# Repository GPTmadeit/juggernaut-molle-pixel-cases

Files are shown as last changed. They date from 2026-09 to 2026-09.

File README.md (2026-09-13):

# Juggernaut-style MOLLE case — Pixel 9 Pro, Pixel 9a and Pixel 6a

Three 3D-printable rugged phone cases that drop into the **unmodified** MOLLE adapter from
msenturk115's *Juggernaut Tactical MOLLE Phone Case*, which was drawn around a Galaxy S8.

Each case was rebuilt around a real 3D model of the phone. Every fit — the adapter, the phone,
the end caps, the button plungers — is verified by boolean intersection, not by eye.
**One printed adapter takes any of the three.**

| | Pixel 9 Pro | Pixel 9a | Pixel 6a |
|---|---|---|---|
| phone | 152.80 × 72.00 × 8.50 mm, R 12.00 | 154.70 × 73.30 × 8.90 mm, R 12.03 | 152.20 × 71.79 × 8.90 mm, R 5.2–5.4 |
| camera | 64.4 × 21.5 mm bar, **3.52 mm proud** | 31.2 × 18.0 mm pill, 0.6 mm proud | 66.9 × 16.7 mm visor, 1.5 mm proud |
| case | 164.43 × 86.59 × 19.00 mm | 166.34 × 86.59 × 17.60 mm | 163.83 × 86.59 × 17.20 mm |
| pocket | 154.00 × 72.90 × 8.80 mm | 155.90 × 74.20 × 9.20 mm | 153.40 × 72.69 × 9.20 mm |
| side wall | 2.55 mm | 1.90 mm | 2.66 mm |
| stretch vs. the S8 original | +3.50 mm | +5.40 mm | +2.90 mm |

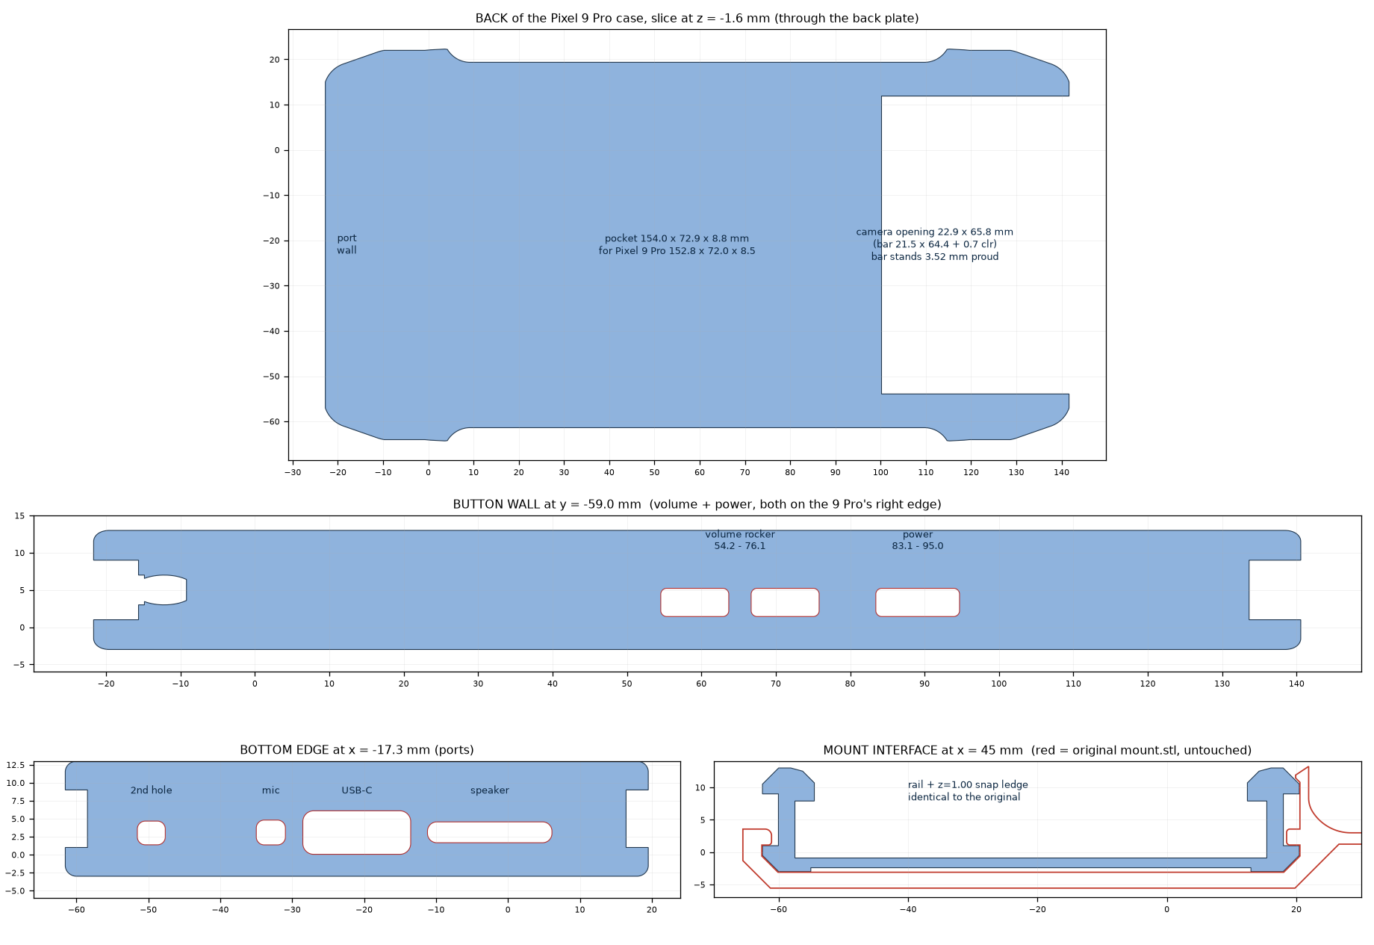
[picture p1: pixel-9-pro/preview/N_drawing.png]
Pixel 9 Pro

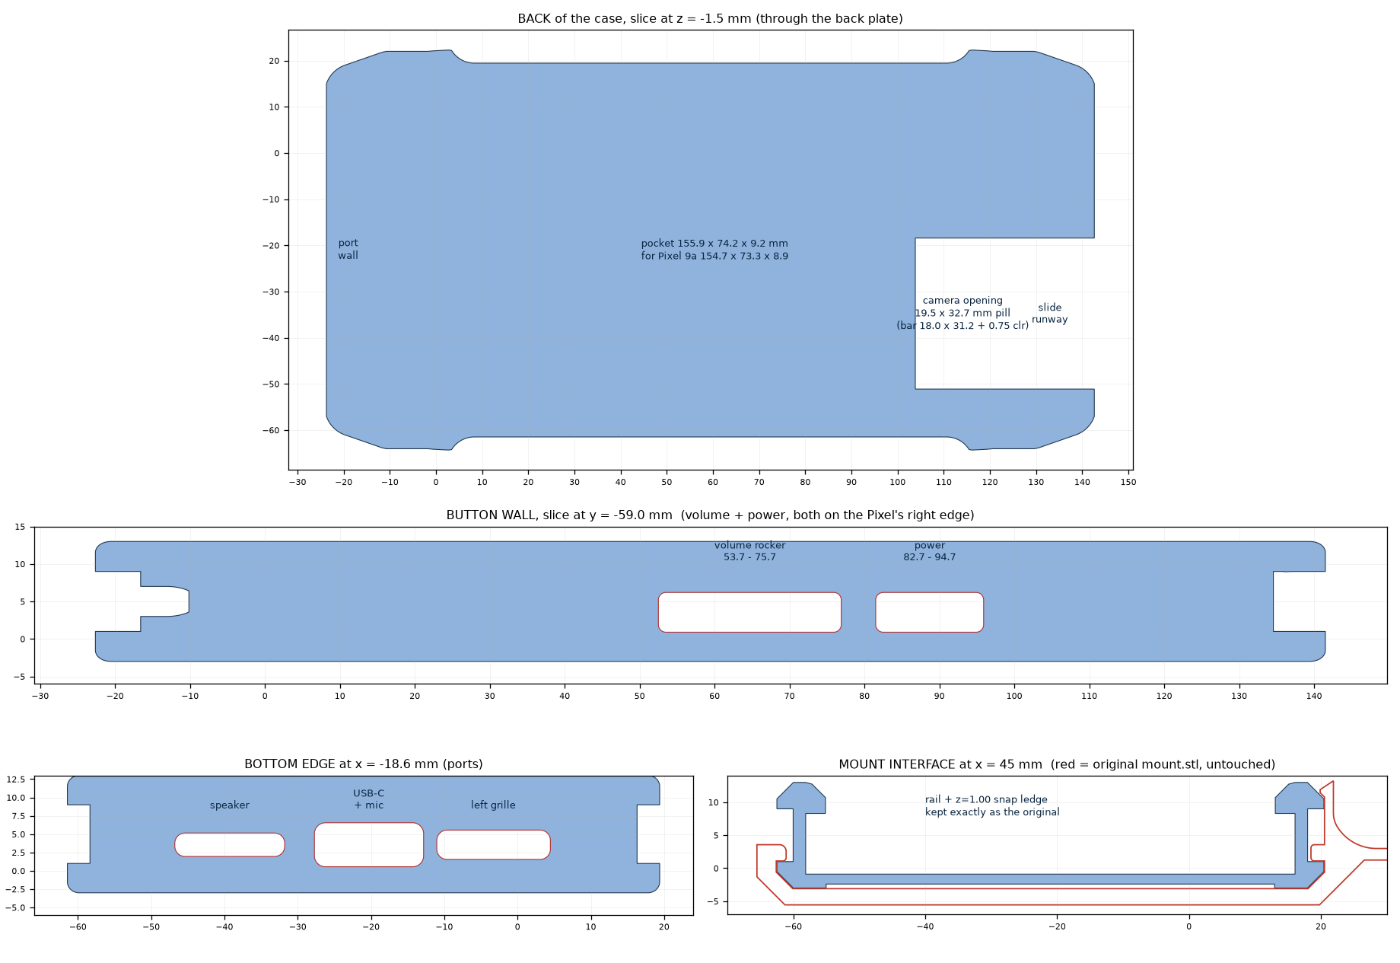
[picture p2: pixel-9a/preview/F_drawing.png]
Pixel 9a

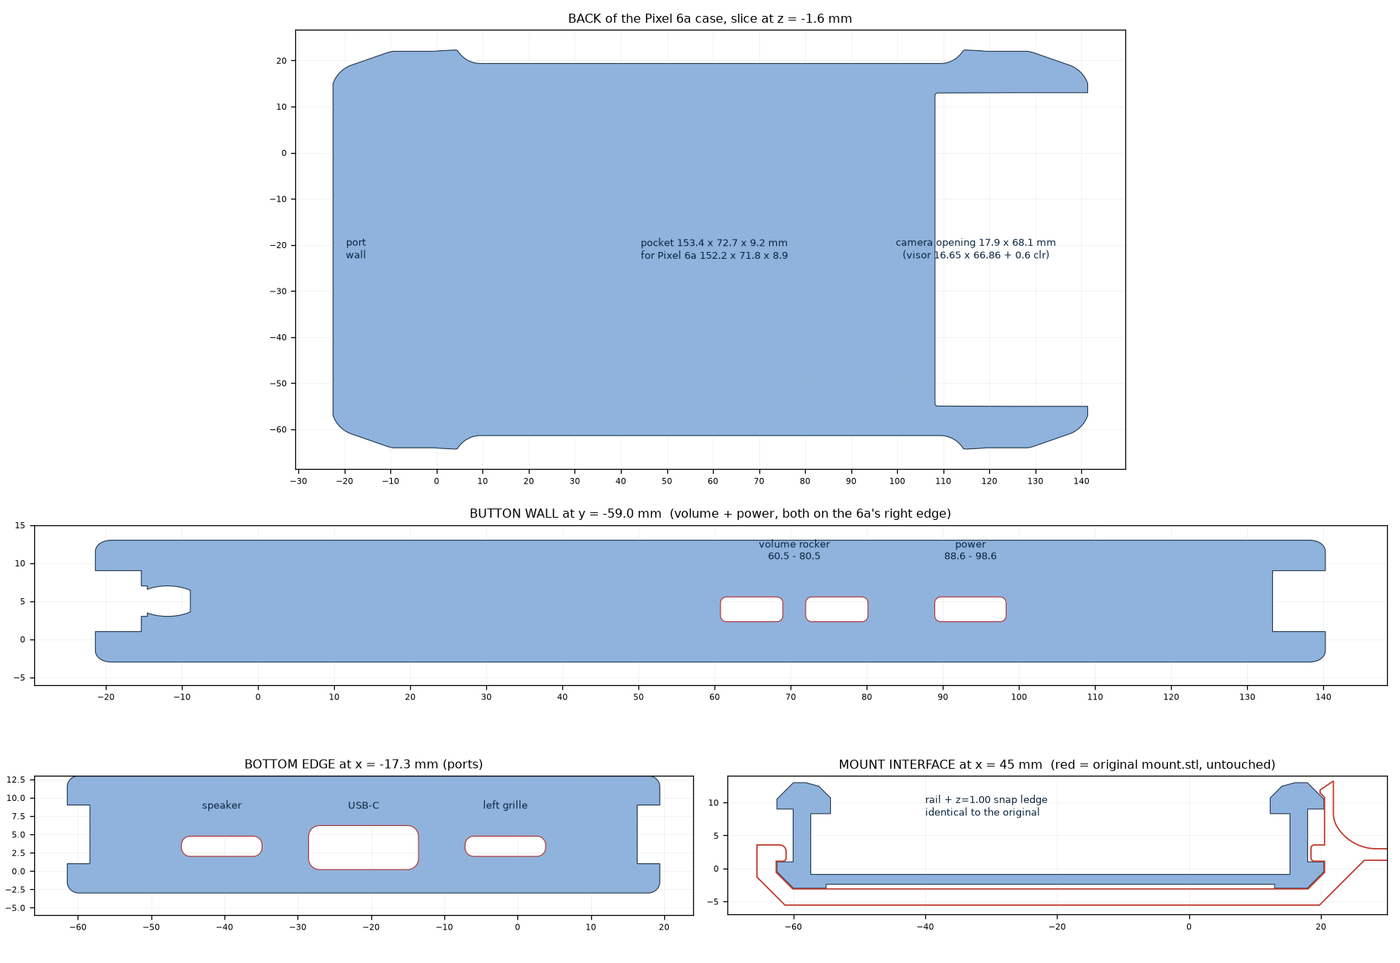
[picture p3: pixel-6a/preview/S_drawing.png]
Pixel 6a


## What's here

```
pixel-9-pro/   pixel-9a/   pixel-6a/      7 STLs + NOTES.md + preview renders
   assembly/                              coloured, fully assembled model (OBJ + 3MF)
shared-mount/                             mount.stl, molle.stl, molle_mount.stl -- ORIGINAL, UNMODIFIED
source/                                   the parametric build + verification scripts
*.zip                                     every STL above in one archive
```

Read each kit's `NOTES.md` for exactly what changed and why.

## Printing

Back (−Z) on the plate, PETG or ABS/ASA, 4 perimeters, 30 % infill or more.

Print the two button plungers first, drop them into their recesses **from inside the pocket**,
then take the top cap off and slide the phone in from the top — the phone traps the plungers.
Use `bottom_cap_for_usb_cable_*` instead of `bottom_cap_*` when you want to charge with the
cap on. If the phone is tight after printing, scale the case to 100.3 % **in X and Y only**.

## How the mount interface is preserved

The adapter grips the case through four spring tabs that hook over a horizontal ledge at
**z = 1.00 mm** in the groove running along both sides of the case. Those tabs sit at
x 36.9–56.9 and 61.9–82.0, with a 4.98 mm tab-free window at x 56.95–61.93.

All three cases therefore keep, untouched:

* outer rail faces y = −62.48 / +20.45, rail underside z = −3.00, and the 45° chamfers
* the side groove (in to y = −60.02 / +17.98, z 1.00 – 9.00) and its z = 1.00 snap ledge
* the groove rib, re-trimmed after the stretch back to x 57.44 – 61.44 so it stays inside the
  tab-free window
* the T-slots at both ends that the end caps slide into

Each case is lengthened by splitting the original at x = 59.5 — inside that tab-free window —
and inserting a slice of its own constant mid-section, so the rail pattern the adapter sees is
unchanged. The button plungers stop at y = −60.95, clear of the tab tips at y = −61.10.

## The camera bump is what makes each case different

The phone has to slide in lengthways with the top cap off, and the camera has to travel with
it. How proud the camera sits dictates the whole back of the case:

* **9a** — 0.6 mm. A 0.70 mm channel in the pocket floor, with a small boss outside to keep the
  plate 1.4 mm.
* **6a** — 1.5 mm. Too deep for a 1.5 mm back plate, so a raised visor shelf carries the channel.
* **9 Pro** — 3.52 mm. A 3.60 mm-proud camera shelf, which is the only reason that case is
  1.4 mm thicker than the other two.

Because that channel must run out through the top-cap socket, each **top cap carries a tongue**
that plugs the trench it would otherwise leave. Shaped by boolean — the trench box minus the
case and the phone, each grown 0.20 mm — so it cannot foul either, and measured against the
stock cap over a full 26 mm withdrawal it adds **+0.0000 mm³** of interference.
See `pixel-9-pro/preview/topcap_gap_before_after.png`.

On the 6a and 9 Pro the camera shelf also runs right to the end of the case, so the **lens cap
is trimmed flush** with the case's end face rather than wrapping around it — otherwise it stood
1.42 mm proud of the top of the phone. See `preview/lenscap_flush_before_after.png`.

## Verified

For all three phones, by boolean intersection (0.000 mm³):

* case ∩ mount.stl — the adapter still seats
* case ∩ phone, seated and at every extreme of the clearance envelope
* the phone slid in from the +X end in 2 mm steps over the full length, at each corner of the
  clearance envelope
* case ∩ and phone ∩ each of the four caps and both button plungers
* every phone feature — speaker, USB-C, mic(s), camera, buttons — unobstructed
* every STL: one body, watertight

Re-run it yourself: see `source/`.

## Rebuilding

```bash
pip install numpy trimesh manifold3d shapely
export JUGG_ROOT=/path/to/work      # holds the extracted original zip + the phone models
python source/pixel9pro/build_case9p.py && python source/pixel9pro/build_parts9p.py
python source/pixel9a/build_case.py   && python source/pixel9a/build_parts.py
python source/pixel6a/build_case6a.py && python source/pixel6a/build_parts6a.py
python source/pixel9pro/topcap_fill.py   # adds the top-cap tongues to all three
python source/finalize.py                # decimate to 5 um and re-verify everything
python source/assembly.py                # coloured assembled models
```

Every dimension lives in `source/<kit>/params*.py`.

## Credit and licence

The original **Juggernaut Tactical MOLLE Phone Case** is by **msenturk115**. The MOLLE adapter,
the end caps, and the case's outer shell and rail geometry are their work; this repo only
refits the phone-facing side for three Pixels. Please check the original model's licence before
selling anything printed from this, and credit msenturk115.

The phone reference models are third-party and are **not** redistributed here — only
measurements taken from them:

* Pixel 9 Pro — `pixel_9_pro.stl` by the1dynasty, [Thingiverse 6746749](https://www.thingiverse.com/thing:6746749)
  (cross-checked against the Pixel 9 Pro XL STEP by Sri Ram on GrabCAD)
* Pixel 6a — `Pixel6AModel.3mf` / `.step`
* Pixel 9a — `pixel9a-phone.stl`

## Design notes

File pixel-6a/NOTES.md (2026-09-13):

# Pixel 6a — what changed from the S8 original

Phone: 152.20 × 71.79 × 8.90 mm, corner radius 5.22–5.41 mm, camera **visor** 66.86 × 16.65 mm
where it meets the back and standing **1.50 mm** proud, power and volume both on the right
edge. Measured from `Pixel6AModel.3mf` — 13 separate solids: body, screen, visor, lenses,
flash, both buttons, and the bottom-edge port recesses.

| # | Change | Reason |
|---|---|---|
| 1 | Case lengthened **+2.90 mm** (slice inserted at x = 59.5, halves moved 1.45 mm apart) | The 6a is 3.3 mm longer than the S8. |
| 2 | Groove rib re-trimmed to x 57.44 – 61.44 | Same tab-clearance reason as the 9a. |
| 3 | Pocket recut to **153.40 × 72.69 × 9.20 mm** | The outline is taken from the phone's own silhouette (port notches filled) offset 0.45 mm/side and 0.60 mm/end, so the 6a's four slightly different corner radii are followed exactly rather than approximated by one radius. |
| 4 | Pocket entrance squared off and carried through the top-cap socket | Slide-in clearance. |
| 5 | Old S8 camera hole and hood deleted, back plate closed | — |
| 6 | New camera opening **17.85 × 68.06 mm** at x 108.20–126.05, y −55.04…13.01 | Visor footprint + 0.60 mm. It spans nearly the full pocket width, leaving a 2.32 mm floor ledge each side — that is simply what a Pixel 6-series visor requires. |
| 7 | **Raised visor shelf** across the back, x 104.90–141.35, 1.80 mm proud, 45° taper | Does the job of the 9a's hood *and* carries the slide channel. The visor ends up recessed 1.8 mm inside it. |
| 8 | Slide channel, floor z = −2.60, from the opening to the top end | The visor is 1.50 mm proud — far too much to clear a 1.5 mm back plate, so the shelf adds the depth from outside. The plate stays 1.60 mm. |
| 9 | Old S8 button holes filled, grooves reopened | — |
| 10 | New button openings on the −Y wall: volume x 60.47–80.45, power x 88.62–98.60, z 2.70–5.15 | Plus a 0.30 mm relief groove; the 6a's buttons stand only 0.40 mm proud. |
| 11 | Bottom wall: three new openings | 6a bottom edge, measured from the model: speaker grille, centred USB-C, left grille. |
| 12 | Screen opening **147.40 × 66.69 mm**, 1.2 mm chamfer, lip underside z = 8.30 | 3.0 mm lip, clearing the 141.3 × 63.6 mm display by 1.6–3.1 mm. |
| 13 | Top cap gains a mic hole | The 6a's top mic sits between the stock cap's two vents. |

## Files

| File | Notes |
|---|---|
| `case_pixel6a.stl` | the case, 163.83 × 86.59 × 17.20 mm |
| `top_cap_pixel6a.stl` | stock cap moved +1.45 mm, new hole over the 6a's top mic |
| `bottom_cap_pixel6a.stl` | stock cap moved −1.45 mm, S8 slots replaced with 6a speaker / left-grille slots |
| `bottom_cap_for_usb_cable_pixel6a.stl` | same, cable window dropped to z 1.55 for the 6a's lower USB-C |
| `volume_button_pixel6a.stl` | two-pad rocker plunger with a thinned centre web |
| `power_button_pixel6a.stl` | single-pad plunger |
| `camera_protector_cap_pixel6a.stl` | wedge-fit cap over the visor shelf; its rim is cut to the case's real back profile so it seats flat |

## Thinnest features

side walls 2.66 mm (2.36 mm across the button relief band) · back plate 1.50 mm
(1.60 mm under the slide channel, inside the shelf) · button flange shoulder 1.56 mm ·
back-plate ledge beside the camera opening 2.32 mm · front lip 3.00 mm wide

The 6a case is the sturdier of the two everywhere except the camera band, where the visor's
width is what dictates the opening.

## Lens cap trimmed flush (added after first print review)

The camera shelf runs right to the end of the case, so the lens cap's end wall wrapped around
the case's end face and stood **1.42 mm proud of the top of the phone**. The cap is now cut off
flush at the case's +X end face — it still wedges on the two tapered side walls and the −X end
wall, and now measures 0.00 mm³ beyond the case. See `preview/lenscap_flush_before_after.png`.

## Top-cap tongue (added after first print review)

The camera slide channel has to run out through the top-cap socket, otherwise the phone can't
be slid in with the cap off. That left a **1.70 mm** open trench between the cap's underside and
the channel floor, open at the case's end face. The top cap now carries a tongue that plugs it,
shaped by boolean (trench box minus the case and the phone, each grown 0.20 mm) so it cannot
foul either. Against the untouched cap over a full 26 mm withdrawal sweep the tongue adds
**+0.0000 mm³** of interference. The case itself is unchanged.
See `../pixel-9-pro/preview/topcap_gap_before_after.png`.

## Charging port (fixed after first print review)

Two things were wrong with the **`bottom_cap_for_usb_cable_*`** caps:

1. The block that erases the stock S8 speaker slots was cut far too wide (Y −50…6) and ran
   straight across the cable window, leaving a **3.4 mm bar through the middle of it**. The old
   slots only occupy Y −44.22…−32.82, so the erase block is now exactly that band.
2. The stock window (Z 2.45…7.55) was aligned to the **S8's** USB-C, which sits 1.5–1.9 mm
   higher in the pocket than these phones'. It is now recut as one clean window at Z 0.80…7.55,
   centred on the actual port.

Measured clear aperture for a plug driven through **cap + case** to the phone's port:

| | before | after |
|---|---|---|
| Pixel 9 Pro | 11.0 × 3.25 mm | **13.0 × 4.00 mm** |
| Pixel 9a | 11.0 × 3.00 mm | **12.5 × 5.00 mm** |
| Pixel 6a | 10.5 × 3.25 mm | **13.0 × 4.25 mm** |

A USB-C plug shell is 8.3 × 2.6 mm, so it passes with room. A chunky cable overmould
(~5–6.5 mm tall) may still not seat fully on the 9 Pro and 6a — the remaining limit is a thin
shelf in the case's cap recess, and removing it only buys another 0.25–0.50 mm, which is not
worth reprinting a case for. Only the caps changed; the cases are untouched.

See `preview/usb_port_before_after.png`.

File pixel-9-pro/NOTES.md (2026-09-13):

# Pixel 9 Pro — Juggernaut MOLLE case

Phone: **152.80 × 72.00 × 8.50 mm**, 12.00 mm corner radius, camera bar **64.44 × 21.50 mm
standing 3.52 mm proud**, power and volume both on the right edge.

Measured from `pixel_9_pro.stl` (the1dynasty, [Thingiverse 6746749](https://www.thingiverse.com/thing:6746749)),
scaled ×1000 — the file is in metres — and repaired (96 zero-area triangles from the Blender
export removed; it then closes cleanly, genus 0).

## Source-model confidence — read this

That dummy was **modelled in Blender from spec sheets before the author had the phone**, so it
is not caliper-measured the way the 9a and 6a models were. What I could check:

* overall size **152.80 × 72.00 × 8.50** matches Google's published figures exactly
* corner radius fits R = 12.00 on three of four corners to within **0.005 mm**
* it *does* carry bottom-edge port recesses (speaker, USB-C with its tongue, mic, one more hole)
  and a top mic — better than I expected
* **its USB-C is dead-centre on the bottom edge (Y = −21.02, the pocket centreline), which the
  independent Pixel 9 Pro XL STEP** (Sri Ram, GrabCAD, converted via OpenCASCADE) **agrees with.**
  Speaker and mic offsets from the centreline agree between the two models to ~1.5 mm.

So: outer dimensions and the camera bar I trust. Port *positions* are the soft spot, which is
why the bottom openings below are cut oversize.

## What changed from the S8 original

| # | Change | Reason |
|---|---|---|
| 1 | Case lengthened **+3.50 mm** (slice inserted at x = 59.5, halves moved 1.75 mm apart) | The 9 Pro is 3.9 mm longer than the S8. |
| 2 | Groove rib re-trimmed to x 57.44 – 61.44 | Keeps it inside the adapter's 4.98 mm tab-free window. |
| 3 | Pocket **154.00 × 72.90 × 8.80 mm**, R 12.45 | 0.60 mm/end, 0.45 mm/side, 0.30 mm depth. |
| 4 | Pocket entrance squared off and carried through the top-cap socket | Slide-in clearance. |
| 5 | Old S8 camera hole and hood deleted, back plate closed | — |
| 6 | New camera opening **22.90 × 65.84 mm**, R 11.15, at x 100.69–123.59, y −53.94…11.90 | Camera bar + 0.70 mm. Leaves a 3.53 mm floor ledge each side. |
| 7 | **Raised camera shelf**, x 97.49–141.65, **3.60 mm proud** (z −6.00 … −2.40), 45° taper | The bar stands 3.52 mm proud — nothing like that clears a 1.5 mm back plate, so the shelf both hoods the bar and provides the depth. |
| 8 | Slide channel, floor z = −4.62, spanning the whole opening to the top end | The bar has to travel from the pocket entrance to its seat. Plate under it stays **1.38 mm**. |
| 9 | Old S8 button holes filled, grooves reopened | — |
| 10 | New button openings on the −Y wall: volume x 54.24–76.13, power x 83.14–95.00, z 1.83–4.82 | Plus a 0.35 mm relief groove; the buttons stand 0.47 mm proud. |
| 11 | Bottom wall: four openings, **cut oversize** (speaker 17.3 × 2.9, USB-C 15.0 × 6.05, mic 4.05 × 3.45, second hole 3.9 × 3.3) | Absorbs the ±1.5 mm of uncertainty in the source model's port positions. |
| 12 | Screen opening **148.00 × 66.90 mm**, 1.2 mm chamfer, lip underside z = 7.90 | 3.0 mm lip all round. |
| 13 | Top cap shifted +1.75 mm, no new mic hole needed | The 9 Pro's top mic (y −45.22…−44.02) already falls inside the stock cap's vent at y −46.54…−43.54. |
| 14 | Top cap gains a **tongue** filling the slide-channel trench | See the section at the bottom. |

## Files

`case_pixel9pro.stl` · `top_cap_pixel9pro.stl` · `bottom_cap_pixel9pro.stl` ·
`bottom_cap_for_usb_cable_pixel9pro.stl` · `volume_button_pixel9pro.stl` ·
`power_button_pixel9pro.stl` · `camera_protector_cap_pixel9pro.stl`

`mount_UNCHANGED.stl`, `molle_UNCHANGED.stl`, `molle_mount_UNCHANGED.stl` — copied from the
original design, **not modified**. The same printed adapter takes the 9a, 6a and 9 Pro cases.

`assembly/` — the coloured, fully assembled model. See `assembly/README.md`.

## Verified by boolean intersection (all 0.000 mm³ or float-noise)

case ∩ mount · case ∩ phone seated and at every clearance extreme · phone slid in from the +X
end in 2 mm steps over the full length at five clearance corners · case ∩ and phone ∩ all four
caps and both plungers · speaker, USB-C, both mics and the camera bar unobstructed ·
every STL single-body and watertight.

## Thinnest features

side walls 2.55 mm (2.20 mm across the button relief band) · back plate 1.50 mm
(1.38 mm under the slide channel, inside the shelf) · button flange shoulder 1.40 mm ·
back-plate ledge beside the camera opening 3.53 mm · front lip 3.00 mm wide

## Printing

Case is **164.4 × 86.6 × 19.0 mm** — 1.4 mm thicker than the 9a's, entirely because of the
camera shelf. Back (−Z) on the plate, PETG or ABS/ASA, 4 perimeters, 30 % infill or more.

Plungers in from inside the pocket first, then top cap off and slide the phone in from the top.
If it's tight, scale the case 100.3 % in X and Y only.

## Top-cap tongue (added after first print review)

The camera-bump slide channel has to run out through the top-cap socket, otherwise the phone
can't be slid in with the cap off. That left an open trench between the cap's underside and
the channel floor, open at the case's end face:

| | trench |
|---|---|
| Pixel 9a | 0.70 mm tall |
| Pixel 6a | 1.70 mm |
| Pixel 9 Pro | 3.72 mm |

Fixed on the **cap**, not the case: the top cap now carries a tongue that plugs the trench,
shaped by boolean (trench box minus the case and the phone, each grown 0.20 mm) so it cannot
foul either. Measured against the untouched cap over a full 26 mm withdrawal sweep, the tongue
adds **+0.0000 mm³** of interference — it slides in and out exactly as the stock cap did.

See `preview/topcap_gap_before_after.png`.

## Lens cap trimmed flush (added after first print review)

The camera shelf runs right to the end of the case, so the lens cap's end wall wrapped around
the case's end face and stood **1.42 mm proud of the top of the phone**. The cap is now cut off
flush at the case's +X end face — it still wedges on the two tapered side walls and the −X end
wall, and now measures 0.00 mm³ beyond the case. See `preview/lenscap_flush_before_after.png`.

## Charging port (fixed after first print review)

Two things were wrong with the **`bottom_cap_for_usb_cable_*`** caps:

1. The block that erases the stock S8 speaker slots was cut far too wide (Y −50…6) and ran
   straight across the cable window, leaving a **3.4 mm bar through the middle of it**. The old
   slots only occupy Y −44.22…−32.82, so the erase block is now exactly that band.
2. The stock window (Z 2.45…7.55) was aligned to the **S8's** USB-C, which sits 1.5–1.9 mm
   higher in the pocket than these phones'. It is now recut as one clean window at Z 0.80…7.55,
   centred on the actual port.

Measured clear aperture for a plug driven through **cap + case** to the phone's port:

| | before | after |
|---|---|---|
| Pixel 9 Pro | 11.0 × 3.25 mm | **13.0 × 4.00 mm** |
| Pixel 9a | 11.0 × 3.00 mm | **12.5 × 5.00 mm** |
| Pixel 6a | 10.5 × 3.25 mm | **13.0 × 4.25 mm** |

A USB-C plug shell is 8.3 × 2.6 mm, so it passes with room. A chunky cable overmould
(~5–6.5 mm tall) may still not seat fully on the 9 Pro and 6a — the remaining limit is a thin
shelf in the case's cap recess, and removing it only buys another 0.25–0.50 mm, which is not
worth reprinting a case for. Only the caps changed; the cases are untouched.

See `preview/usb_port_before_after.png`.

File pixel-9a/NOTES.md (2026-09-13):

# Pixel 9a — what changed from the S8 original

Phone: 154.70 × 73.30 × 8.90 mm, 12.03 mm corner radius, camera bar 31.2 × 18.0 mm standing
0.60 mm proud, power and volume both on the right edge. Measured from `pixel9a-phone.stl`.

| # | Change | Reason |
|---|---|---|
| 1 | Case lengthened **+5.40 mm** (slice inserted at x = 59.5, halves moved 2.70 mm apart) | The 9a is 5.8 mm longer than the S8. |
| 2 | Groove rib re-trimmed to x 57.44 – 61.44 | The stretch grew it to 9.4 mm; the adapter's tabs need it inside their 4.98 mm gap. |
| 3 | Pocket recut to **155.90 × 74.20 × 9.20 mm**, R 12.48 | 0.60 mm/end, 0.45 mm/side, 0.30 mm depth. The original was 3.9 mm loose across — it was sized for a phone already in a slim case. |
| 4 | Pocket entrance squared off and carried through the top-cap socket | Lets the phone slide straight in once the top cap is off. |
| 5 | Old S8 camera hole and hood deleted, back plate closed | Wrong size, wrong place. |
| 6 | New camera opening: **19.5 × 32.7 mm pill** at x 104.33–123.83, y −51.12…−18.42 | Camera bar + 0.75 mm; pill shape matches the bar. |
| 7 | New hood, 2.2 mm proud, 45° taper, 3.0 mm rim | Same idea as the original hood; starts past x = 97.34 so it can't touch the adapter. |
| 8 | **Camera slide runway** — 0.70 mm channel in the pocket floor from the opening to the top end, with a boss outside | The bar is 0.60 mm proud; without this it jams on the pocket floor going in. The boss keeps the plate 1.40 mm. |
| 9 | Old S8 button holes filled, grooves reopened | The 9a has both buttons on one edge; the S8 had them split. |
| 10 | New button openings on the −Y wall: volume x 53.70–75.70, power x 82.70–94.70, z 2.05–5.05 | Plus a 0.40 mm relief groove along the slide path for the 0.6 mm-proud buttons. |
| 11 | Bottom wall: S8 holes (4 slots + USB + 3.5 mm jack) filled, three new openings cut | 9a bottom edge: speaker grille, centred USB-C + mic, left grille. No headphone jack. |
| 12 | Screen opening **149.90 × 68.20 mm**, R 9.48, 1.2 mm chamfer, lip underside z = 8.30 | 3.0 mm lip: about 2.6 mm of overlap on the phone's front face, clearing the 146.1 × 65.1 mm display by 1.5–1.9 mm. |
| 13 | Recessed back window widened around the hood | Gives the lens cap a flat seat; entirely past the adapter. |

## Files

| File | Notes |
|---|---|
| `case_pixel9a.stl` | the case, 166.34 × 86.59 × 17.60 mm |
| `top_cap_pixel9a.stl` | stock cap moved +2.70 mm; its existing vent already lines up with the 9a's top mic |
| `bottom_cap_pixel9a.stl` | stock cap moved −2.70 mm, S8 slots replaced with 9a speaker / mic / left-grille slots (USB stays covered) |
| `bottom_cap_for_usb_cable_pixel9a.stl` | same, cable window dropped to z 1.95 so a plug clears the port |
| `volume_button_pixel9a.stl` | two-pad rocker plunger with a thinned centre web |
| `power_button_pixel9a.stl` | single-pad plunger |
| `camera_protector_cap_pixel9a.stl` | wedge-fit lens cap for the new hood, with grip ribs |

## Thinnest features

side walls 1.90 mm (1.50 mm across the button relief band) · back plate 1.50 mm
(1.40 mm under the runway; one 1.7 mm-wide bridge at x 126.8–128.5 is 0.80 mm) ·
button flange shoulder 0.70 mm · front lip 3.00 mm wide

## Top-cap tongue (added after first print review)

The camera slide channel has to run out through the top-cap socket, otherwise the phone can't
be slid in with the cap off. That left a **0.70 mm** open trench between the cap's underside and
the channel floor, open at the case's end face. The top cap now carries a tongue that plugs it,
shaped by boolean (trench box minus the case and the phone, each grown 0.20 mm) so it cannot
foul either. Against the untouched cap over a full 26 mm withdrawal sweep the tongue adds
**+0.0000 mm³** of interference. The case itself is unchanged.
See `../pixel-9-pro/preview/topcap_gap_before_after.png`.

## Charging port (fixed after first print review)

Two things were wrong with the **`bottom_cap_for_usb_cable_*`** caps:

1. The block that erases the stock S8 speaker slots was cut far too wide (Y −50…6) and ran
   straight across the cable window, leaving a **3.4 mm bar through the middle of it**. The old
   slots only occupy Y −44.22…−32.82, so the erase block is now exactly that band.
2. The stock window (Z 2.45…7.55) was aligned to the **S8's** USB-C, which sits 1.5–1.9 mm
   higher in the pocket than these phones'. It is now recut as one clean window at Z 0.80…7.55,
   centred on the actual port.

Measured clear aperture for a plug driven through **cap + case** to the phone's port:

| | before | after |
|---|---|---|
| Pixel 9 Pro | 11.0 × 3.25 mm | **13.0 × 4.00 mm** |
| Pixel 9a | 11.0 × 3.00 mm | **12.5 × 5.00 mm** |
| Pixel 6a | 10.5 × 3.25 mm | **13.0 × 4.25 mm** |

A USB-C plug shell is 8.3 × 2.6 mm, so it passes with room. A chunky cable overmould
(~5–6.5 mm tall) may still not seat fully on the 9 Pro and 6a — the remaining limit is a thin
shelf in the case's cap recess, and removing it only buys another 0.25–0.50 mm, which is not
worth reprinting a case for. Only the caps changed; the cases are untouched.

See `preview/usb_port_before_after.png`.

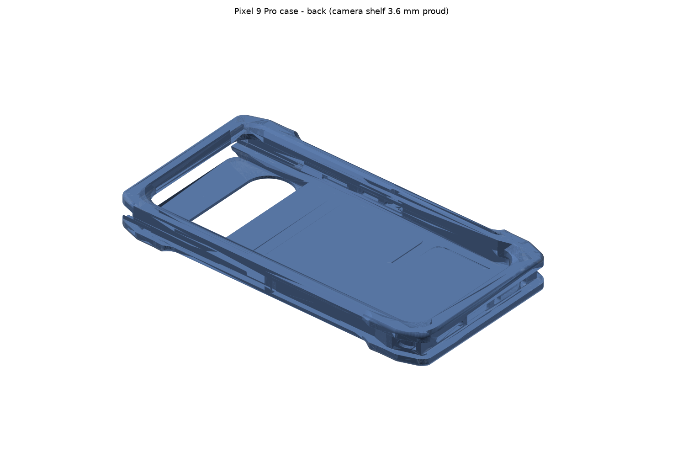
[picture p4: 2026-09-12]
pixel-9-pro/preview/N_case_back.png

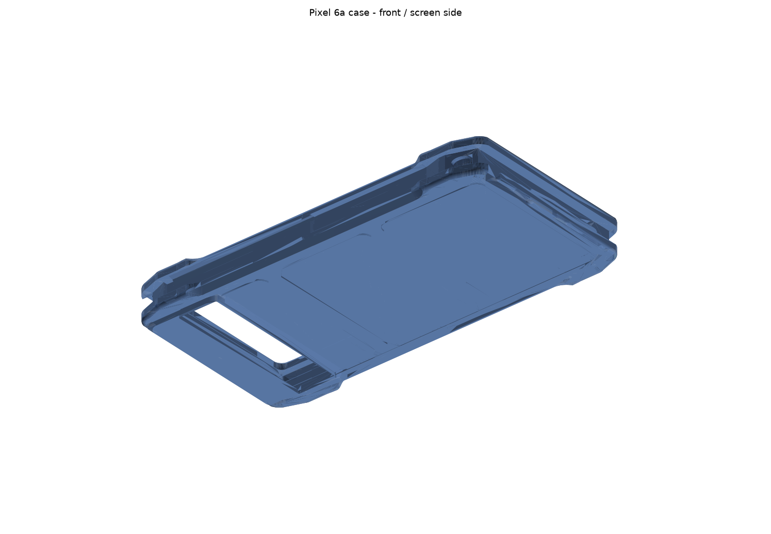
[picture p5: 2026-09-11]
pixel-6a/preview/S_case_front.png

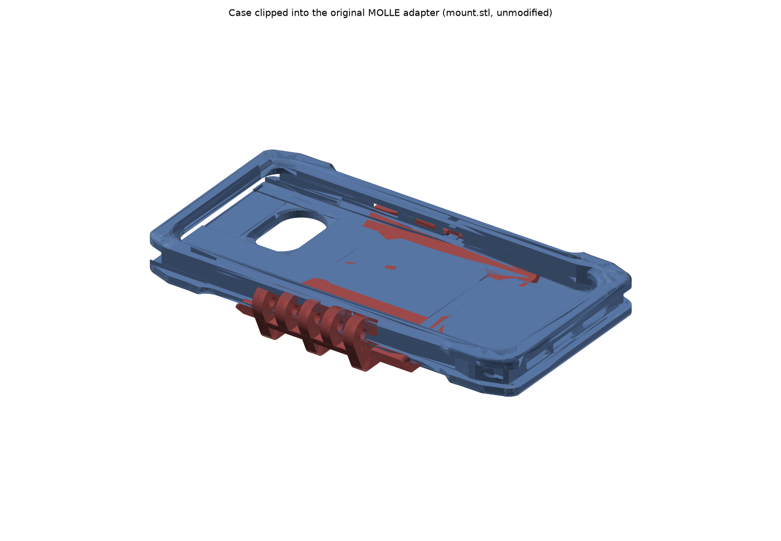
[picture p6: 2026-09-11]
pixel-9a/preview/F_case_mount.png

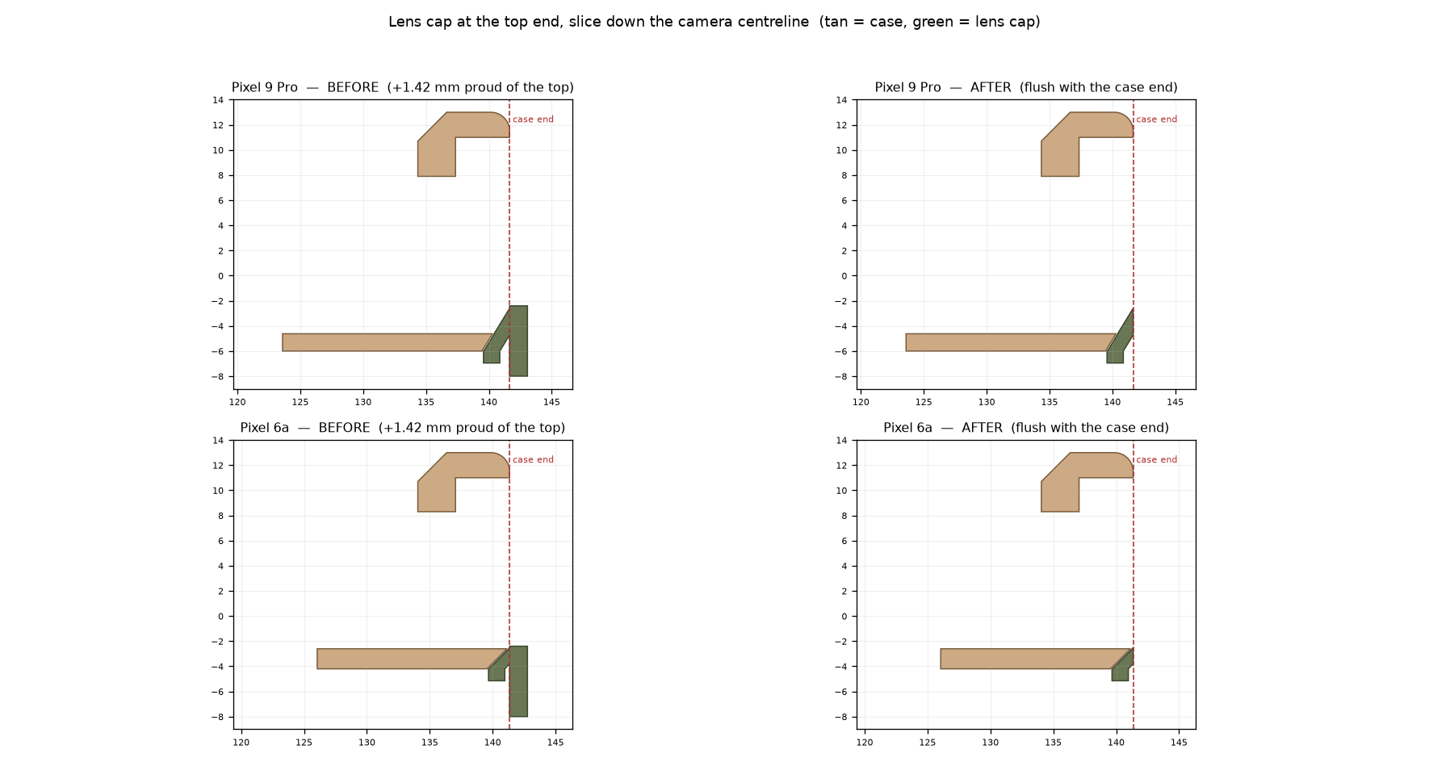
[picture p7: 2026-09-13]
pixel-6a/preview/lenscap_flush_before_after.png

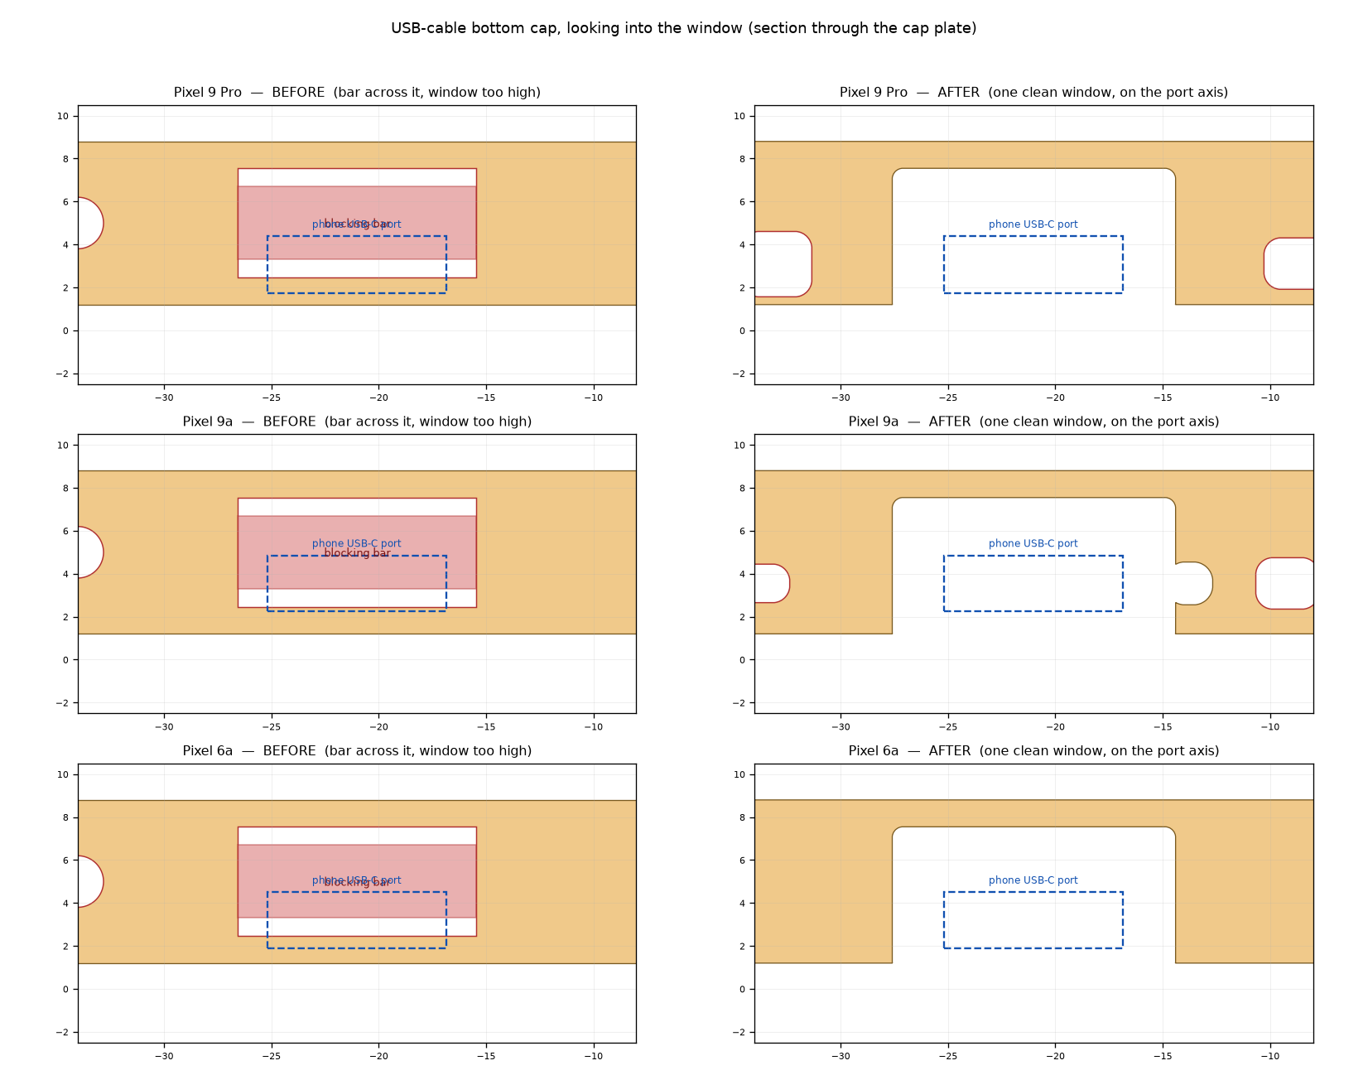
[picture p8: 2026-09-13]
pixel-9a/preview/usb_port_before_after.png

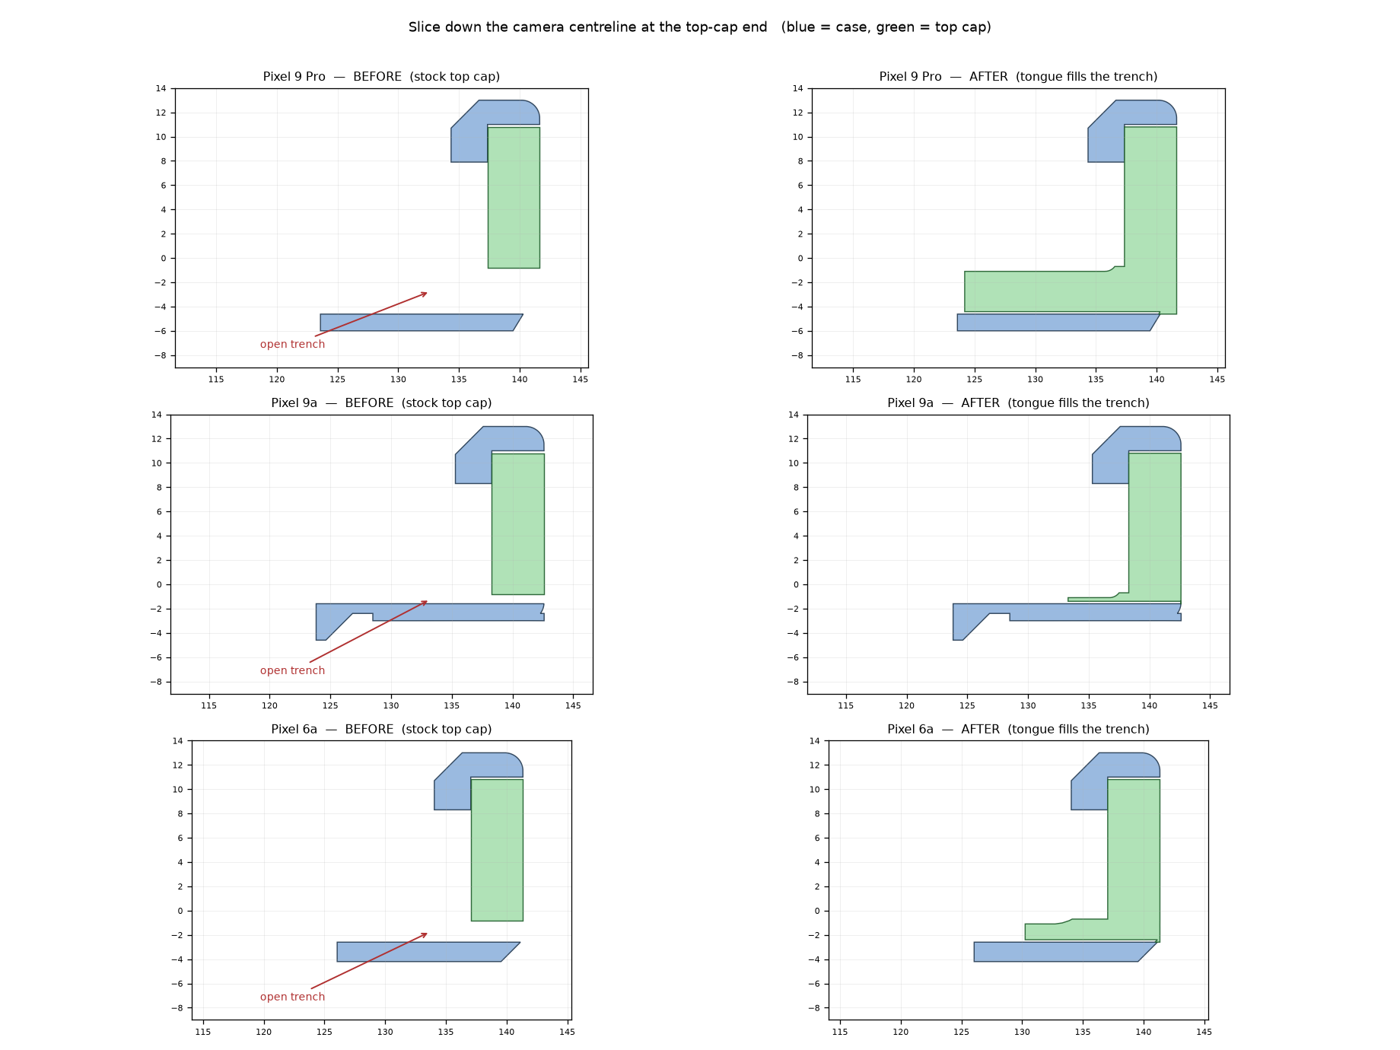
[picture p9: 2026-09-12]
pixel-9a/preview/topcap_gap_before_after.png

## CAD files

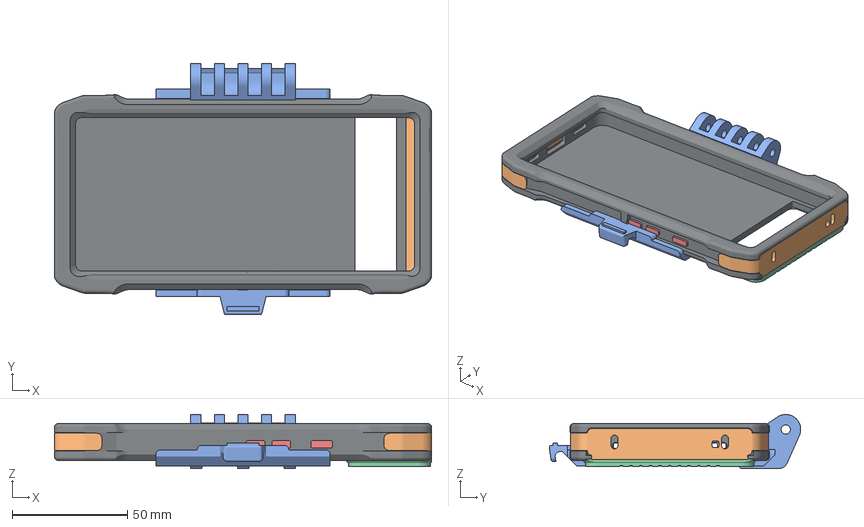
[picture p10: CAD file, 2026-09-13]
pixel-6a/assembly/pixel6a_assembly.3mf
163.8 x 109.3 x 23.5 mm
case
top_cap
bottom_cap
volume_button
power_button
camera_protector_cap
molle_adapter

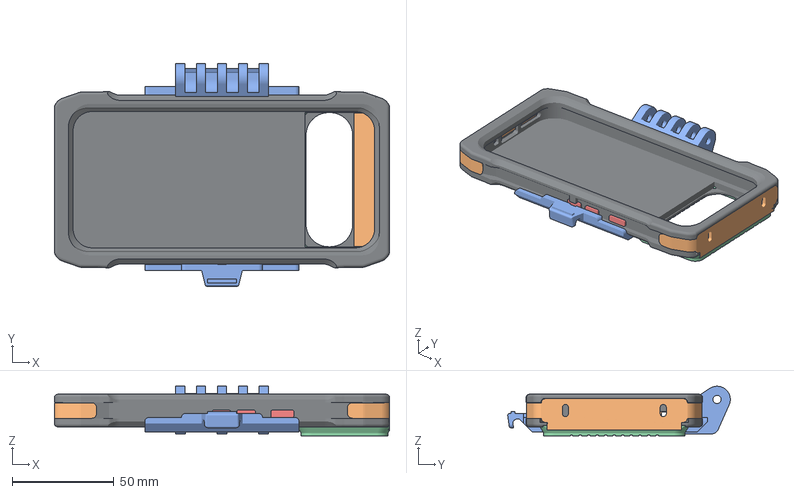
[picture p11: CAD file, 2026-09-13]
pixel-9-pro/assembly/pixel9pro_assembly.3mf
164.4 x 109.3 x 24.3 mm
case
top_cap
bottom_cap
volume_button
power_button
camera_protector_cap
molle_adapter

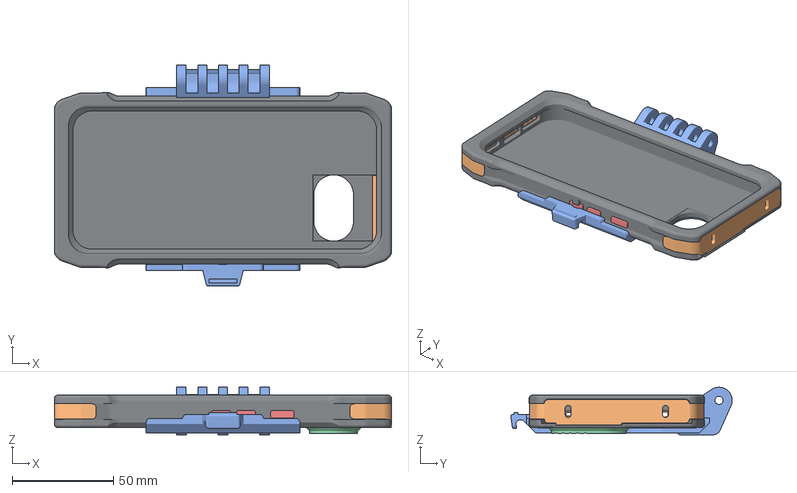
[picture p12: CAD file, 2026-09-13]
pixel-9a/assembly/pixel9a_assembly.3mf
166.3 x 109.3 x 23.5 mm
case
top_cap
bottom_cap
volume_button
power_button
camera_protector_cap
molle_adapter

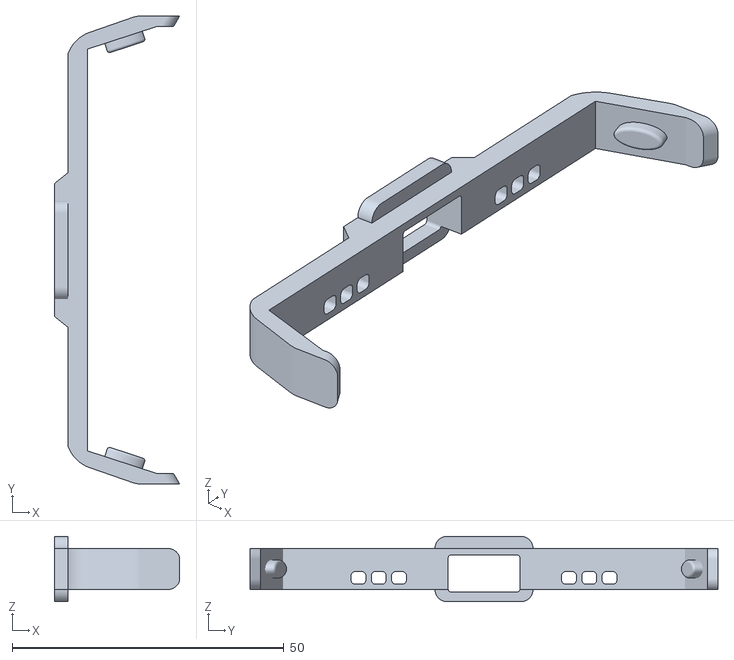
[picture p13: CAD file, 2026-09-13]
pixel-6a/bottom_cap_for_usb_cable_pixel6a.stl
23.0 x 86.0 x 12.0

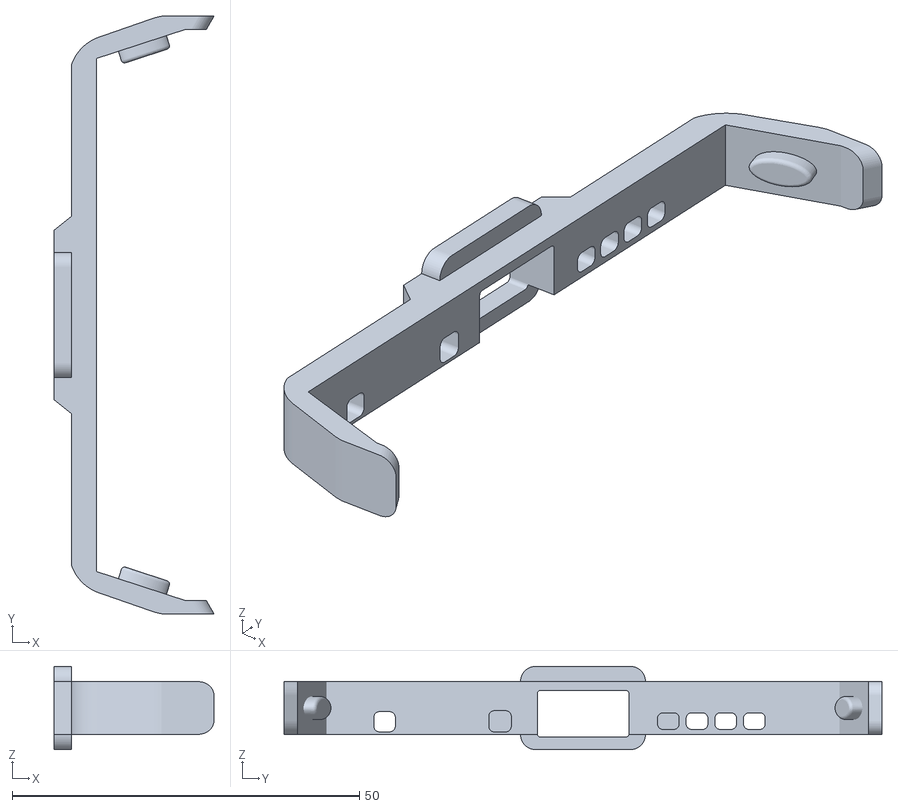
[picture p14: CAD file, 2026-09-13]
pixel-9-pro/bottom_cap_for_usb_cable_pixel9pro.stl
23.0 x 86.0 x 12.0

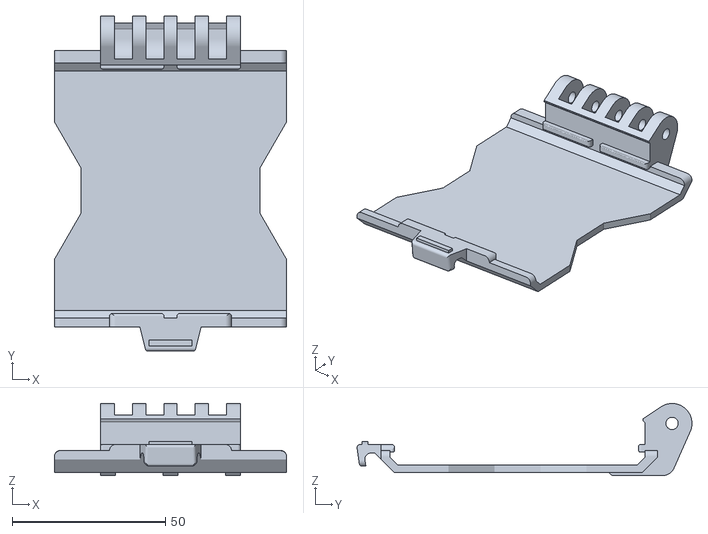
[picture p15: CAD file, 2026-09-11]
shared-mount/mount.stl
75.8 x 109.3 x 23.5

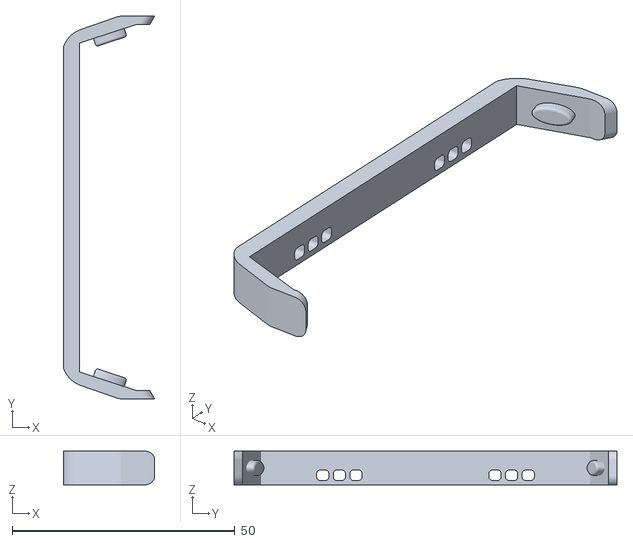
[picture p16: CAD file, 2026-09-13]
pixel-6a/bottom_cap_pixel6a.stl
20.5 x 86.0 x 7.60

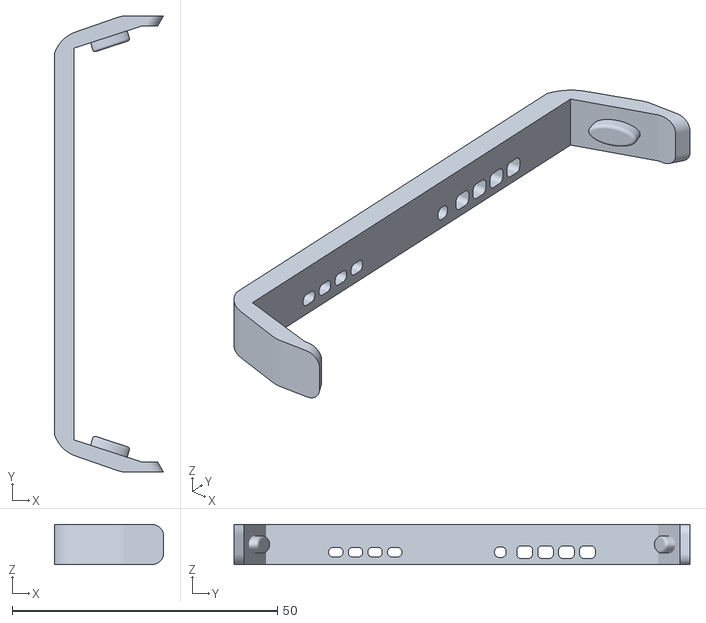
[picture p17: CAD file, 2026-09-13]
pixel-9a/bottom_cap_pixel9a.stl
20.5 x 86.0 x 7.60

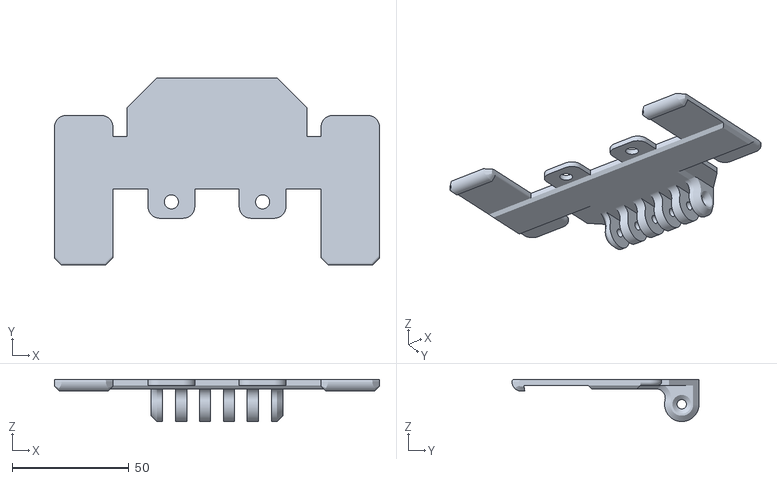
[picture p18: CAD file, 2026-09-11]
shared-mount/molle_mount.stl
139.0 x 80.0 x 18.0

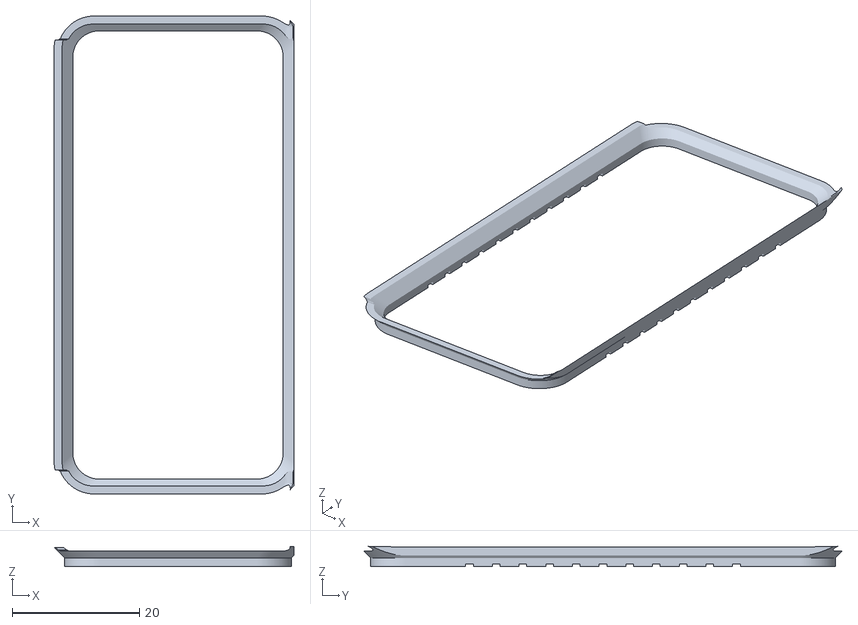
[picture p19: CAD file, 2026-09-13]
pixel-6a/camera_protector_cap_pixel6a.stl
37.7 x 75.2 x 3.20

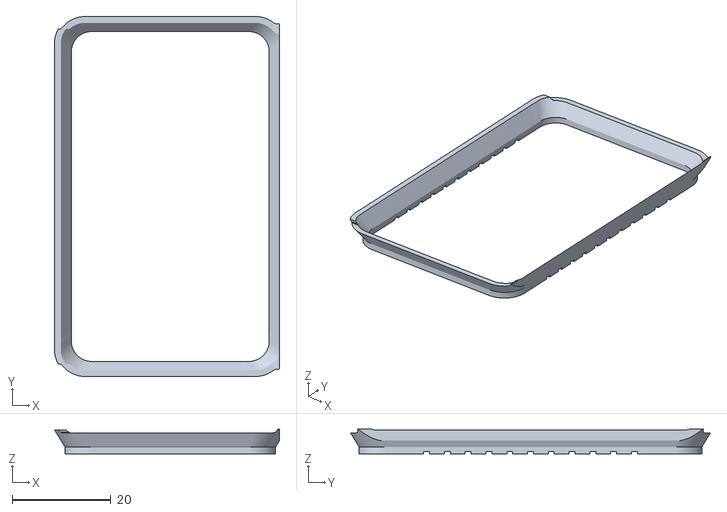
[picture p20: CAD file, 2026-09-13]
pixel-9-pro/camera_protector_cap_pixel9pro.stl
45.5 x 72.8 x 5.00

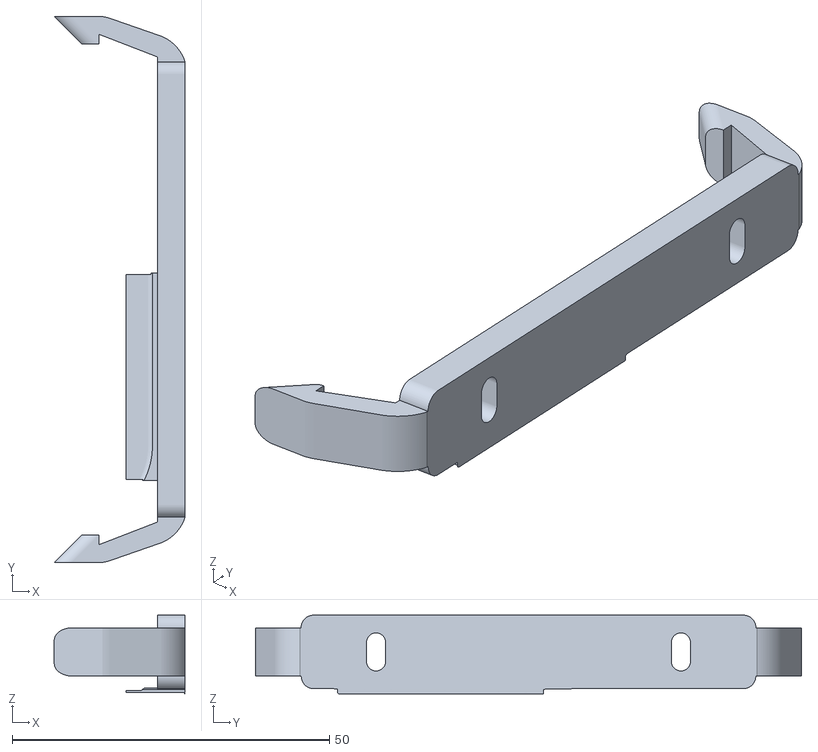
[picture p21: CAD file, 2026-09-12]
pixel-9a/top_cap_pixel9a.stl
20.6 x 86.0 x 12.4

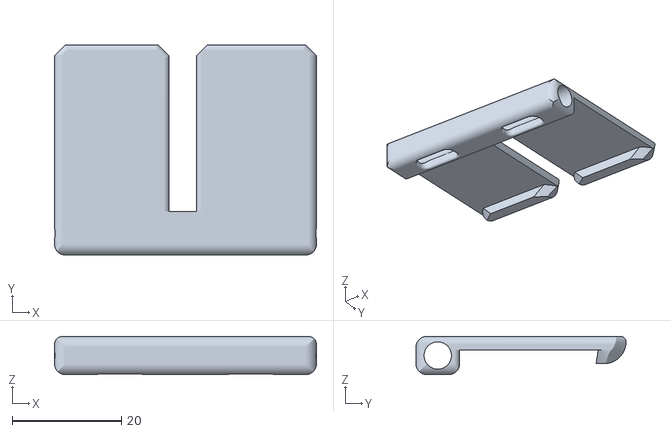
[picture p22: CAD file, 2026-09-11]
shared-mount/molle.stl
48.0 x 38.5 x 7.00

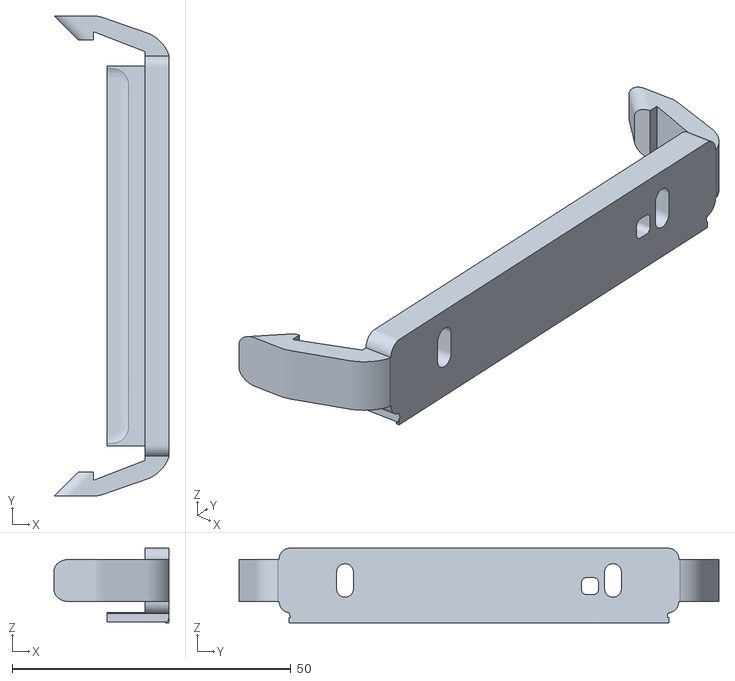
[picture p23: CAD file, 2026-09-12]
pixel-6a/top_cap_pixel6a.stl
20.6 x 86.0 x 13.4

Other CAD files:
pixel-9a/bottom_cap_for_usb_cable_pixel9a.stl
pixel-9-pro/bottom_cap_pixel9pro.stl
pixel-9-pro/top_cap_pixel9pro.stl
pixel-9a/volume_button_pixel9a.stl
pixel-6a/assembly/pixel6a_assembly.obj
pixel-6a/case_pixel6a.stl
pixel-6a/power_button_pixel6a.stl
pixel-6a/volume_button_pixel6a.stl
pixel-9-pro/assembly/pixel9pro_assembly.obj
pixel-9-pro/case_pixel9pro.stl
pixel-9-pro/power_button_pixel9pro.stl
pixel-9-pro/volume_button_pixel9pro.stl
pixel-9a/assembly/pixel9a_assembly.obj
pixel-9a/camera_protector_cap_pixel9a.stl
pixel-9a/case_pixel9a.stl
pixel-9a/power_button_pixel9a.stl

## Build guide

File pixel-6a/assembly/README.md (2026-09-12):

# Assembled, per-part coloured model

**The STLs in the parent folder are already in assembly coordinates** — the case, both caps,
both plungers, the lens cap and `../../shared-mount/mount.stl` all share one frame, so nothing
needs moving. Import them and they belong where they land.

The two files here carry the same thing with colours and positions baked into a single import:

| file | what it's for |
|---|---|
| `*_assembly.obj` + `.mtl` | one import, 7 named parts, already positioned. Tinkercad accepts `.obj`; whether it reads the `.mtl` colours I can't confirm — if not, the parts are still separate and colourable by hand. Keep the `.mtl` beside the `.obj`. |
| `*_assembly.3mf` | 7 named objects with colours baked in. This is the one that definitely renders in colour — Bambu Studio, PrusaSlicer, Cura, Windows 3D Viewer. |

Colours: case dark slate · caps orange · buttons red · lens cap green · MOLLE adapter blue.

The phone reference models are **not** included here — they're third-party CAD and this repo
doesn't redistribute them. See each kit's NOTES for where to get them.

This is a visualisation, not a print layout. Print from the STLs in the parent folder.

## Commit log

2026-09-11 Pixel 9a and Pixel 6a conversions of the Juggernaut MOLLE case
    Refits msenturk115's Galaxy S8 Juggernaut Tactical MOLLE case to the Pixel 9a
    and Pixel 6a, keeping the MOLLE adapter (mount.stl) completely unmodified.
    Both cases are lengthened by inserting a slice of the original's own constant
    mid-section at x=59.5 -- inside the adapter's 4.98 mm tab-free window -- so the
    rail, side groove and z=1.00 snap ledge the adapter grips are untouched. The
    groove rib is re-trimmed afterwards to stay inside that window.
    Each pocket, screen opening, camera opening, button cutout and port is derived
    from a real 3D model of the phone. The 6a additionally gets a raised visor shelf
    that both hoods the 1.5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
    [bottom_cap_for_usb_cable_pixel6a.stl, bottom_cap_for_usb_cable_pixel9a.stl, bottom_cap_pixel6a.stl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]
2026-09-12 Add the Pixel 9 Pro kit, close the top-cap trench, add coloured assemblies
    Pixel 9 Pro
    New third kit, same pipeline. Its camera bar stands 3.52 mm proud -- six times
    the 9a's -- so the case gets a 3.60 mm raised camera shelf that both hoods the
    bar and carries the slide-in channel. That is the only reason it is 1.4 mm
    thicker than the other two.
    The source dummy was modelled from spec sheets rather than measured, so the
    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
    [bottom_cap_for_usb_cable_pixel9pro.stl, bottom_cap_pixel9pro.stl, camera_protector_cap_pixel9pro.stl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]
2026-09-13 Trim the 6a and 9 Pro lens caps flush with the top of the case
    On those two kits the camera shelf runs right to the end of the case, so the
    lens cap's end wall wrapped around the case's end face and stood 1.42 mm proud
    of the top of the phone. Both caps are now cut off flush at the case's +X end
    face: 0.00 mm^3 beyond the case, down from 107.31 (9 Pro) and 68.71 (6a).
    They still wedge on the two tapered side walls and the -X end wall, so retention
    is unaffected. The 9a's cap sits 14 mm inside the case end and never had the
    problem; its geometry is unchanged.
    Cases, end caps and button plungers are all untouched. Assemblies and the
    combined zip regenerated. All three kits re-verified: case/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
    [camera_protector_cap_pixel6a.stl, camera_protector_cap_pixel9pro.stl, pixel6a_assembly.3mf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]
2026-09-13 Unblock the charging port on the USB-cable bottom caps
    Two defects, both in bottom_cap_for_usb_cable_*:
    1. The block that erases the stock S8 speaker slots spanned Y -50..6 and ran
    straight across the cable window, leaving a 3.4 mm bar through the middle of
    it -- the port was unusable. The old slots only occupy Y -44.22..-32.82, so
    the erase block is now exactly that band.
    2. The stock window (Z 2.45..7.55) was aligned to the S8's USB-C, which sits
    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
    [bottom_cap_for_usb_cable_pixel6a.stl, bottom_cap_for_usb_cable_pixel9a.stl, bottom_cap_for_usb_cable_pixel9pro.stl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]
